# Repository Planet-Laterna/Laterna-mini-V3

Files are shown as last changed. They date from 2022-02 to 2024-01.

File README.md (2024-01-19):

<h1>Laterna mini V3</h1>

The Laterna series of boards are mainly intended to be used with [WLED software ](https://github.com/Aircoookie/WLED "WLED's Homepage"), but you can also program the board using your own code or other library via [Arduino](https://www.arduino.cc "Arduino Homepage"), [ESPHome](https://esphome.io "ESPHome Homepage"), [Tasmota](https://tasmota.github.io/docs "Tasmota Homepage") etc.

The controller can be ordered from [Aliexpress](https://www.aliexpress.us/item/3256804573459837.html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)<br>

<h3>Features</h3>
Chip:   ESP32-Pico-mini
<br>USB Type C connector for flashing and 5V power
<br>CP2102 or CH340 USB to serial chip for easy flashing
<br>1 channel for adressable LED strip incl. level shifter (e.g. WS281x, SK6812 etc.)
<br>3A resettable Fuse (https://en.wikipedia.org/wiki/Resettable_fuse)
<br>Version with and without integrated digital Microphone available (INMP441)

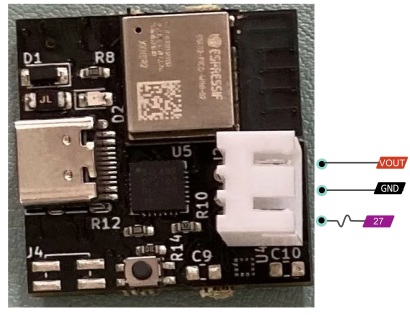
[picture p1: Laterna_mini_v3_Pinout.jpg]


<h3>Installation</h3>

All our boards are delivered with a up to date WLED version.You can use the board out of the box.

You can customize the software based on your needs and flash it by **USB** or the **programming connector**.
The board has an integrated CP2102 USB to UART bridge so you can flash it without using **any additional hardware**.

For Flashing a precompiled Firmware we recommend [ESPHome Flasher](https://github.com/esphome/esphome-flasher/releases "ESPHome Flasher Releases")

We also have a ESPHome template available which can be easily flashed via [this website](https://planet-laterna.github.io/Laterna-ESPHome-template)

<h5>Required steps for manual flashing</h5>

* First you need to put the Board in flash mode
* Press and hold the Flash button before connecting the board to USB or programmer connector. Release the flash button after you connect the board.

<h3>Circuit protection</h3>

Our boards include a resetable fuses to limit current on the board.
<br>Powered by USB C port -> 3A

<h3>Tested LED Strips:</h3>
WS281x
<br>SK6812

<h3>Use Cases - Videos</h3> 

Laterna Mini Ambilight (https://www.youtube.com/watch?v=7gAAEo-JBUc)

Iron Man Suit by Nate from the Internet

Iron Man (https://youtu.be/u2959fVrq-s?si=skSPCmUmJoFIo4mM&t=94)

<h3>License</h3>

Software used in this guide is open source and licensed under the **MIT License**

<h3>FAQ</h3>

* Can I use this board with my own code?
  - yes, you can write your own code and programm this board. Refer to programming steps section

<h3>Acknowledgment</h3>

We would like to thank WLED Developers for their great job, our platform relies strongly on their work

(https://github.com/Aircoookie/WLED)

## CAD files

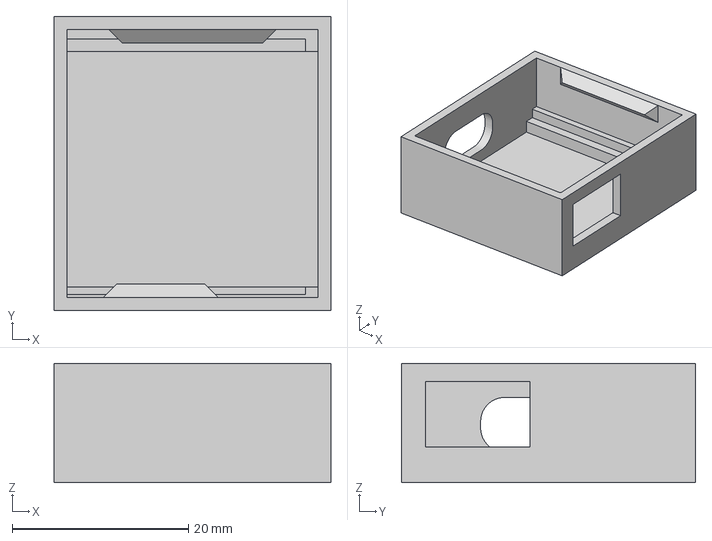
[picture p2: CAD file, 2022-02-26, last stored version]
Case/Case.3mf
31.4 x 33.4 x 13.5 mm

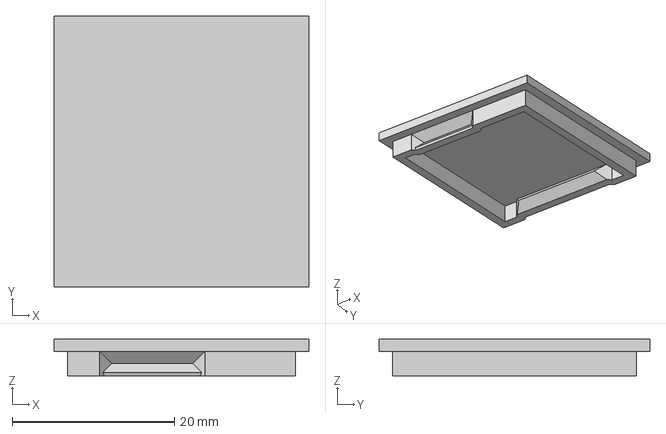
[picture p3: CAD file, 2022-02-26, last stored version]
Case/Top.3mf
31.4 x 33.4 x 4.50 mm

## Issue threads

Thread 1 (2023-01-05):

Pinout

mulbc, 2023-01-05:
Could you please add a pinout diagram like for the other projects please?

monoapp3, 2023-06-26:
sorry for missing this query, we are updating this diagram and hope to have soon online.

PIN used for ledstrip is GPIO 27

numindast, 2023-06-26:
Thank you for this.

Will you be able to provide any detail about the output circuit? Is it straight off the esp32 or is there a level shifter? I've been trying to troubleshoot some LED glitching and find the output voltage a bit low. (Without a resistor the voltage rises a bit but the LEDs get very glitchy.)

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

numindast, 2023-06-26:
Figured out some more details, thought I'd add a comment for future info seekers.

AudioReactive setup:

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

Latest release of WLED-SR (0.14.0-b15) as of this writing flashed successfully, and sound works & everything. Look for the "[WLEDMM_0.14.0-b15.21_esp32_pico_4MB_M.bin](https://github.com/MoonModules/WLED/releases/download/v0.14.0.b15/WLEDMM_0.14.0-b15.21_esp32_pico_4MB_M.bin)" release (you may have to expand the list)

[https://github.com/MoonModules/WLED/releases](url)

monoapp3, 2023-06-27:
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

created a new issue for this, please check https://github.com/Planet-Laterna/Laterna-mini-V3/issues/3

monoapp3, 2023-06-27:
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

thanks for confirming sound reactive functionality with newest WLED version.
We will include this also in our documentation

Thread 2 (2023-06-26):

What's the solder pads for?

numindast, 2023-06-26:
Labelled "J4"

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

monoapp3, 2023-06-27:
For some setups it is possible to use a small speaker or  for other purposes

J4 is intended for this. Not delivered in default configuration, but you can use it , it is enabled.

Pinout ( J4 is pin 1 and clockwise counting)

1) GPIO 13
2) GND       (R-)
3) GPIO 25 ( R+)
4) 5V

numindast, 2023-06-27:
Oh that's cool! That could be very handy!

The red light is indeed the Laterna's power LED. I detailed the hookup in [Issue #1 here](https://github.com/Planet-Laterna/Laterna-mini-V3/issues/1).

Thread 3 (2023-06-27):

Observed glitches with latest WLED bin

monoapp3, 2023-06-27:
Thank you for this.

Will you be able to provide any detail about the output circuit? Is it straight off the esp32 or is there a level shifter? I've been trying to troubleshoot some LED glitching and find the output voltage a bit low. (Without a resistor the voltage rises a bit but the LEDs get very glitchy.)

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

_Originally posted by @numindast in https://github.com/Planet-Laterna/Laterna-mini-V3/issues/1#issuecomment-1608034527_

monoapp3, 2023-06-27:
@numindast could you please explain a little bit more on detail your setup.

We did not observe such a problem during our sanity tests. We are using a much older WLED version for testing. 0.12.x

Besides different software used:
- which type of LEDs are you using ?
- how many of them ?
- how do you power the board?

Remark: all our boards have a level shifter

thanks

numindast, 2023-06-27:
Thanks for your reply!

I'm going to do further tests. This might be specific to a particular type of strand I have ([these from aliexpress](https://www.aliexpress.us/item/3256801832370301.html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)). I tested 3 separate bundles of 50 LEDs and found using a 220ohm resistor on the data line would drive them reliably. These are 50 LEDs per string, and the total length is 5 meters. I'm thinking I will re-test with power injection at both ends.

When I switched to a more typical LED strip with 22 ws2812b's over a 36cm length (a little over 13 inches), I'm finding reliable operation without a resistor. However I haven't put my scope on this (laterna+small strip) yet and I bet it will look different with a short strip compared to the 5m long string.

I've used both a 40w (8a/5v) Alitove supply and a little 12.5w (2.5a/5v) d-link wall wart. Incidentally I have not checked the output voltage on both, and I will check them.

I'm using WAGO connectors to make a V+ and V- bus with a 2200uF electrolytic cap between them to smooth out power flow. The strip and Laterna both draw power off those. I have a pair of small WAGO connectors for the data line to give me a test point for the scope and a place to add in the resistor. This is just a "lab bench" setup.

I'm happy to admit my scope is a cheap Owon with a cheap probe. And I'm not very good at operating scopes. However, I saw a much cleaner flat-topped square wave reaching 5v coming off a "yawl-controller" (esp8266 based mini controller) when substituted for the Laterna. I did this so I'd have something to compare against. That's when I thought I should ask :)

I love how small the Laterna Mini v3 is! So many possibilities!
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

monoapp3, 2023-06-27:
interesting to see how you are powering. We usually use USB C for this, since the number of leds is not high it should be possible for you to use that setup ( if not tried yet) if you externally power the led strip as you are doing there is should be a problem.

We used similar led strip on one of our videos, if interested have a loop in our instagram @planetlaterna

Glad to hear you like the footprint!

monoapp3, 2023-06-28:
> Is powering the Mini v3 via USB-C the preferred way to power it (and the LEDs) ? Just want to clarify if back-powering the Mini the way I have is acceptable or not.
>
> Thx :)

it is ok, no problem on that. from setup point of view, the usb c interface reduces the number of cables used.
you would need similar setup as yours in case you would like to inject power..

like to see the flexibility of the board !

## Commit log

2022-02-26 Upload Case
    [Case.3mf, Top.3mf]
2022-06-02 Update Wiring instructions
2022-06-02 update wiring
2022-10-13 Update for V3
    [Case.3mf, Top.3mf]
2023-09-04 Use Case added
